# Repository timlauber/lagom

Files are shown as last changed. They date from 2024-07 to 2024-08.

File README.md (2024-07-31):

# lagom
Lagom is an easy to build 65% keyboard using ~~only~~ some through hole components. It uses a separate microcontroller (like the Pro Micro, Elite C or something RP2040 based) to enable flexibility in firmware and connectivity and to further simplify the soldering experience (no more tricksy USB ports). Demultiplexers and a custom matrix are used to enable the size and features of the board with only the pinouts of a pro micro.

## Changes
This version replaces most trough hole components for SMD variants, but keeps visuals. A power switch as well as a battery connector is added for full wireless support. Only ISO layout is supported.

lagom

**Original lagom kits are available for sale at [sthlmkb.com](https://sthlmkb.com/shop/lagom-keyboard-kit/)**

[License](LICENSE)

Lagom is licensed under the [Creative Commons Attribution-NonCommercial 4.0 International license](https://creativecommons.org/licenses/by-nc/4.0/). This design as it stands in this repository may be freely reproduced, modified, and manufactured for PERSONAL USE ONLY and may not be reproduced in physical form for public sale. 

## Features
* ~~Only through hole components for easy soldering~~
* Separate microcontroller using Pro micro, Elite C, Nice! Nano or equivalent footprint. So micro USB, USB-C or Bluetooth are all options!
* 2 rotary encoders
* OLED screen
* Optional underglow RGB lighting with a WS2812b light strip
* ~~Multiple layout options including ISO, ANSI, split space (2.25u + 1.25u + 2.75u), 7u space, split left shift (1.25u + 1u) and stepped capslock ([layout]("http://www.keyboard-layout-editor.com/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,15&_x:0.25%3B&=2,15&_x:0.25%3B&=0,0%0A%0A%0A%0A%0A%0A%0A%0A%0Ae&=0,1%0A%0A%0A%0A%0A%0A%0A%0A%0Ae%3B&@_y:0.25%3B&=0,0&=0,1&=0,2&=0,3&=0,4&=0,5&=0,6&=0,7&=0,8&=0,9&=0,10&=0,11&=0,12&_w:2%3B&=0,14%0A%0A%0A0,0&=0,15&_x:0.25%3B&=1,0%0A%0A%0A%0A%0A%0A%0A%0A%0Ae&=1,1%0A%0A%0A%0A%0A%0A%0A%0A%0Ae%3B&@_w:1.5%3B&=1,0&=1,1&=1,2&=1,3&=1,4&=1,5&=1,6&=1,7&=1,8&=1,9&=1,10&=1,11&=1,12&_w:1.5%3B&=1,13%0A%0A%0A1,0&=1,14%3B&@_w:1.75%3B&=2,0&=2,1&=2,2&=2,3&=2,4&=2,5&=2,6&=2,7&=2,8&=2,9&=2,10&=2,11&_w:2.25%3B&=2,13%0A%0A%0A1,0&=2,14%3B&@_w:2.25%3B&=3,0%0A%0A%0A2,0&=3,2&=3,3&=3,4&=3,5&=3,6&=3,7&=3,8&=3,9&=3,10&=3,11&_w:1.75%3B&=3,12&=3,13&=3,14%3B&@_w:1.25%3B&=4,0%0A%0A%0A3,0&_w:1.25%3B&=4,1%0A%0A%0A3,0&_w:1.25%3B&=4,2%0A%0A%0A3,0&_w:6.25%3B&=4,6%0A%0A%0A3,0&_w:1.25%3B&=4,10%0A%0A%0A3,0&_w:1.25%3B&=4,11%0A%0A%0A3,0&_x:0.5%3B&=4,12&=4,13&=4,14%3B&@_y:0.5&w:1.25%3B&=4,0%0A%0A%0A3,1&_w:1.25%3B&=4,1%0A%0A%0A3,1&_w:1.25%3B&=4,2%0A%0A%0A3,1&_w:2.25%3B&=4,4%0A%0A%0A3,1&_w:1.25%3B&=4,6%0A%0A%0A3,1&_w:2.75%3B&=4,8%0A%0A%0A3,1&_w:1.25%3B&=4,10%0A%0A%0A3,1&_w:1.25%3B&=4,11%0A%0A%0A3,1%3B&@_y:-0.25&x:15&w:1.25&h:2&w2:1.5&h2:1&x2:-0.25%3B&=2,13%0A%0A%0A1,1%3B&@_y:-0.75&w:1.5%3B&=4,0%0A%0A%0A3,2&=4,1%0A%0A%0A3,2&_w:1.5%3B&=4,2%0A%0A%0A3,2&_w:7%3B&=4,6%0A%0A%0A3,2&_w:1.5%3B&=4,11%0A%0A%0A3,2%3B&@_y:-0.25&x:14%3B&=2,12%0A%0A%0A1,1%3B&@_w:1.25%3B&=3,0%0A%0A%0A2,1&=3,1%0A%0A%0A2,1&_x:9.75%3B&=0,13%0A%0A%0A0,1&=0,14%0A%0A%0A0,1"))~~
* Open and visible components (in the style of Plaid, Romac etc)
* Simple, beautiful and flexible sandwich case out of FR4 (pcb material)

lagom layout

## Components required - To be determined!
* PCB
* FR4 Switch plate
* FR4 Base 
* Controller (I used a Pro Micro in the guide but anything that shares the footprint and pinout will be fine e.g. Elite C, Nice! Nano, or something RP2040 powered!)
* Diodes 1N4148 (74)
* 0.1μF Capacitor (2)
* 16 pin IC socket (2)
* IC (74HC138N) demultiplexer (2)
* Switches (5 pin MX footprint) (up to 72 depending on layout)
* Rotary encoders (2)
* Rotary encoder knobs (2)
* 0.91" OLED screen
* 10mm M2 Standoffs (9 required if mounting the base to the plate)
* 6mm x M2 screws for attaching the standoffs to the plate/base (2 per standoff so 18 total)
* Acrylic cover for the components at the top (optional, not included)
* Stabilisers (PCB mount) (5 x 2u or 3 x 2u + 6.25u or 3 x 2u + 7u depending on layout)
* Rubber feet for the base

Build guide for this version is not available.
[Original build guide available here](https://github.com/mohoyt/lagom/blob/main/build_guide.md)

lagom base

lagom lagom pcb

## Known issues 
None yet! 

## Where to buy
Lagom kits are available for sale exclusively at [sthlmkb.com](https://sthlmkb.com/shop/lagom-keyboard-kit/)

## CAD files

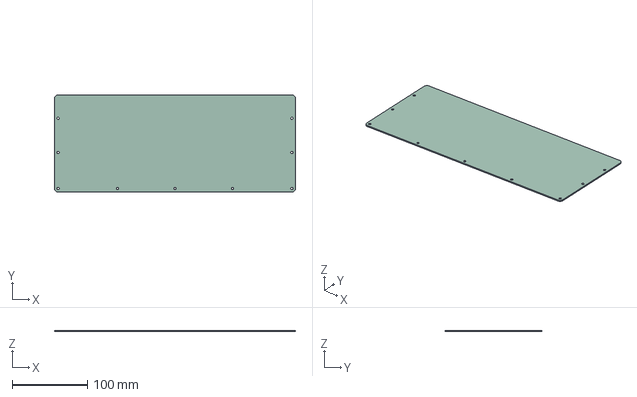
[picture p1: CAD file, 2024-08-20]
PCB/lagom_base/lagom_base.step
319.9 x 128.9 x 1.60 mm

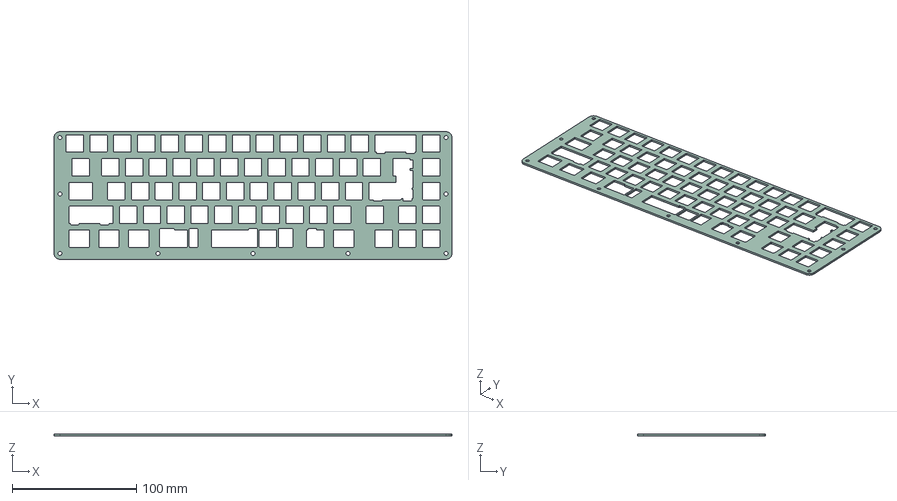
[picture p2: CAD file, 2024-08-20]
PCB/lagom_plate/lagom_plate.step
319.9 x 102.7 x 1.60 mm

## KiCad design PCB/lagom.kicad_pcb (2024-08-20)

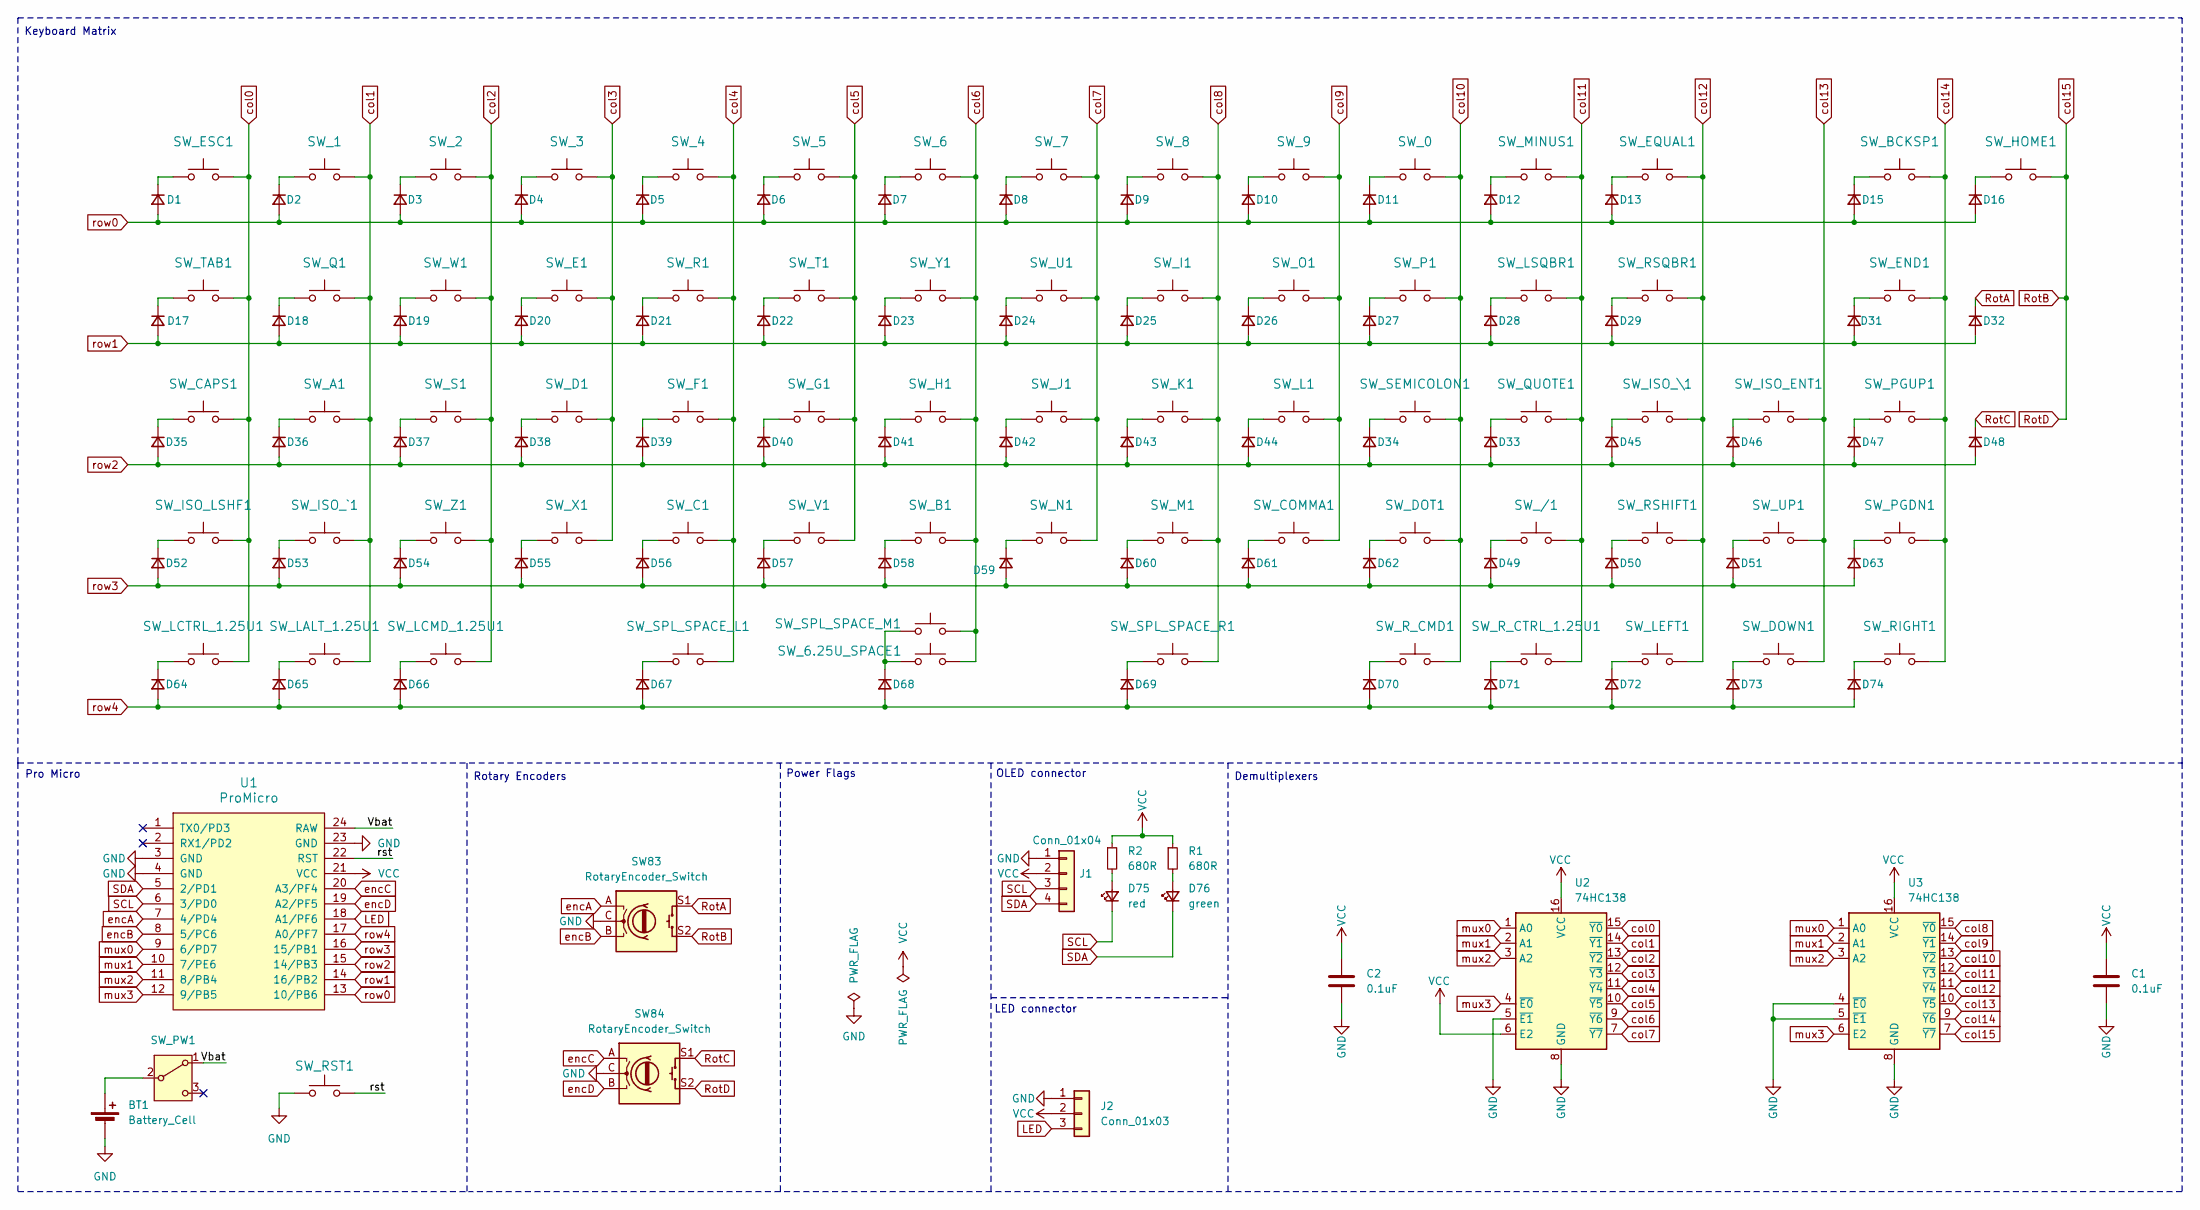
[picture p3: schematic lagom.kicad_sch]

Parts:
BT1: Battery_Cell; JST_PH_S2B-PH-K_1x02_P2.00mm_Horizontal
C1, C2: 0.1uF; C_0805_2012Metric
D1, D2, D3, D4, D5, D6, D7, D8, D9, D10, D11, D12, D13, D15, D16, D17, D18, D19, D20, D21, D22, D23, D24, D25, D26, D27, D28, D29, D31, D32, D33, D34, D35, D36, D37, D38, D39, D40, D41, D42, D43, D44, D45, D46, D47, D48, D49, D50, D51, D52, D53, D54, D55, D56, D57, D58, D59, D60, D61, D62, D63, D64, D65, D66, D67, D68, D69, D70, D71, D72, D73, D74: 1N4148; D_MiniMELF_noSilk
D75: red; LED_1206_3216Metric
D76: green; LED_1206_3216Metric
J1: Conn_01x04; PinSocket_1x04_P2.54mm_Vertical
J2: Conn_01x03; PinSocket_1x03_P2.54mm_Vertical
R1, R2: 680R; R_1206_3216Metric
SW83, SW84: RotaryEncoder_Switch; RotaryEncoder_Alps_EC11E-Switch_Vertical_H20mm
SW_0, SW_1, SW_2, SW_3, SW_4, SW_5, SW_6, SW_7, SW_8, SW_9: KEYSW; SW_Kailh_HotSwap_1.00u_PCB
SW_6.25U_SPACE1: KEYSW; SW_Kailh_HotSwap_6.25u_PCB_reverse
SW_/1: KEYSW; SW_Kailh_HotSwap_1.00u_PCB
SW_A1: KEYSW; SW_Kailh_HotSwap_1.00u_PCB
SW_B1: KEYSW; SW_Kailh_HotSwap_1.00u_PCB
SW_BCKSP1: KEYSW; SW_Kailh_HotSwap_2.00u_PCB
SW_C1: KEYSW; SW_Kailh_HotSwap_1.00u_PCB
SW_CAPS1: KEYSW; SW_Kailh_HotSwap_1.75u_PCB
SW_COMMA1: KEYSW; SW_Kailh_HotSwap_1.00u_PCB
SW_D1: KEYSW; SW_Kailh_HotSwap_1.00u_PCB
SW_DOT1: KEYSW; SW_Kailh_HotSwap_1.00u_PCB
SW_DOWN1: KEYSW; SW_Kailh_HotSwap_1.00u_PCB
SW_E1: KEYSW; SW_Kailh_HotSwap_1.00u_PCB
SW_END1: KEYSW; SW_Kailh_HotSwap_1.00u_PCB
SW_EQUAL1: KEYSW; SW_Kailh_HotSwap_1.00u_PCB
SW_ESC1: KEYSW; SW_Kailh_HotSwap_1.00u_PCB
SW_F1: KEYSW; SW_Kailh_HotSwap_1.00u_PCB
SW_G1: KEYSW; SW_Kailh_HotSwap_1.00u_PCB
SW_H1: KEYSW; SW_Kailh_HotSwap_1.00u_PCB
SW_HOME1: KEYSW; SW_Kailh_HotSwap_1.00u_PCB
SW_I1: KEYSW; SW_Kailh_HotSwap_1.00u_PCB
SW_ISO_ENT1: KEYSW; SW_Kailh_HotSwap_ISOEnter_PCB
SW_ISO_LSHF1: KEYSW; SW_Kailh_HotSwap_1.25u_PCB
SW_ISO_\1: KEYSW; SW_Kailh_HotSwap_1.00u_PCB
SW_ISO_`1: KEYSW; SW_Kailh_HotSwap_1.00u_PCB
SW_J1: KEYSW; SW_Kailh_HotSwap_1.00u_PCB
SW_K1: KEYSW; SW_Kailh_HotSwap_1.00u_PCB
SW_L1: KEYSW; SW_Kailh_HotSwap_1.00u_PCB
SW_LALT_1.25U1: KEYSW; SW_Kailh_HotSwap_1.25u_PCB
SW_LCMD_1.25U1: KEYSW; SW_Kailh_HotSwap_1.25u_PCB
SW_LCTRL_1.25U1: KEYSW; SW_Kailh_HotSwap_1.25u_PCB
SW_LEFT1: KEYSW; SW_Kailh_HotSwap_1.00u_PCB
SW_LSQBR1: KEYSW; SW_Kailh_HotSwap_1.00u_PCB
SW_M1: KEYSW; SW_Kailh_HotSwap_1.00u_PCB
SW_MINUS1: KEYSW; SW_Kailh_HotSwap_1.00u_PCB
SW_N1: KEYSW; SW_Kailh_HotSwap_1.00u_PCB
SW_O1: KEYSW; SW_Kailh_HotSwap_1.00u_PCB
SW_P1: KEYSW; SW_Kailh_HotSwap_1.00u_PCB
SW_PGDN1: KEYSW; SW_Kailh_HotSwap_1.00u_PCB
SW_PGUP1: KEYSW; SW_Kailh_HotSwap_1.00u_PCB
SW_PW1: SW_SPDT; PinHeader_1x03_P2.54mm_Vertical
SW_Q1: KEYSW; SW_Kailh_HotSwap_1.00u_PCB
SW_QUOTE1: KEYSW; SW_Kailh_HotSwap_1.00u_PCB
SW_R1: KEYSW; SW_Kailh_HotSwap_1.00u_PCB
SW_RIGHT1: KEYSW; SW_Kailh_HotSwap_1.00u_PCB
SW_RSHIFT1: KEYSW; SW_Kailh_HotSwap_1.75u_PCB
SW_RSQBR1: KEYSW; SW_Kailh_HotSwap_1.00u_PCB
SW_RST1: KEYSW; SW_PUSH_1P1T_6x3.5mm_H5.0_APEM_MJTP1250
SW_R_CMD1: KEYSW; SW_Kailh_HotSwap_1.25u_PCB
SW_R_CTRL_1.25U1: KEYSW; SW_Kailh_HotSwap_1.25u_PCB
SW_S1: KEYSW; SW_Kailh_HotSwap_1.00u_PCB
SW_SEMICOLON1: KEYSW; SW_Kailh_HotSwap_1.00u_PCB
SW_SPL_SPACE_L1: KEYSW; SW_Kailh_HotSwap_2.25u_PCB_reverse
SW_SPL_SPACE_M1: KEYSW; SW_Kailh_HotSwap_1.25u_PCB
SW_SPL_SPACE_R1: KEYSW; SW_Kailh_HotSwap_2.75u_PCB_reverse
SW_T1: KEYSW; SW_Kailh_HotSwap_1.00u_PCB
SW_TAB1: KEYSW; SW_Kailh_HotSwap_1.50u_PCB
SW_U1: KEYSW; SW_Kailh_HotSwap_1.00u_PCB
SW_UP1: KEYSW; SW_Kailh_HotSwap_1.00u_PCB
SW_V1: KEYSW; SW_Kailh_HotSwap_1.00u_PCB
SW_W1: KEYSW; SW_Kailh_HotSwap_1.00u_PCB
SW_X1: KEYSW; SW_Kailh_HotSwap_1.00u_PCB
SW_Y1: KEYSW; SW_Kailh_HotSwap_1.00u_PCB
SW_Z1: KEYSW; SW_Kailh_HotSwap_1.00u_PCB
U1: ProMicro; ArduinoProMicro-ZigZag
U2, U3: 74HC138; SOIC-16_3.9x9.9mm_P1.27mm

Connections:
/Vbat: SW_PW1.1 (A), U1.24 (RAW)
/rst: SW_RST1.2, U1.22 (RST)
GND: BT1.2 (-), C1.2, C2.2, J1.1, J2.1, SW83.C, SW84.C, SW_RST1.1, U1.3 (GND), U1.4 (GND), U1.23 (GND), U2.5 (~E1), U2.8 (GND), U3.4 (~E0), U3.5 (~E1), U3.8 (GND)
LED: J2.3, U1.18 (A1/PF6)
unnamed: BT1.1 (+), SW_PW1.2 (B)
unnamed: D1.1 (K), SW_ESC1.1
unnamed: D2.1 (K), SW_1.1
unnamed: D3.1 (K), SW_2.1
unnamed: D4.1 (K), SW_3.1
unnamed: D5.1 (K), SW_4.1
unnamed: D6.1 (K), SW_5.1
unnamed: D7.1 (K), SW_6.1
unnamed: D8.1 (K), SW_7.1
unnamed: D9.1 (K), SW_8.1
unnamed: D10.1 (K), SW_9.1
unnamed: D11.1 (K), SW_0.1
unnamed: D12.1 (K), SW_MINUS1.1
unnamed: D13.1 (K), SW_EQUAL1.1
unnamed: D15.1 (K), SW_BCKSP1.1
unnamed: D16.1 (K), SW_HOME1.1
unnamed: D17.1 (K), SW_TAB1.1
unnamed: D18.1 (K), SW_Q1.1
unnamed: D19.1 (K), SW_W1.1
unnamed: D20.1 (K), SW_E1.1
unnamed: D21.1 (K), SW_R1.1
unnamed: D22.1 (K), SW_T1.1
unnamed: D23.1 (K), SW_Y1.1
unnamed: D24.1 (K), SW_U1.1
unnamed: D25.1 (K), SW_I1.1
unnamed: D26.1 (K), SW_O1.1
unnamed: D27.1 (K), SW_P1.1
unnamed: D28.1 (K), SW_LSQBR1.1
unnamed: D29.1 (K), SW_RSQBR1.1
unnamed: D31.1 (K), SW_END1.1
unnamed: D33.1 (K), SW_QUOTE1.1
unnamed: D34.1 (K), SW_SEMICOLON1.1
unnamed: D35.1 (K), SW_CAPS1.1
unnamed: D36.1 (K), SW_A1.1
unnamed: D37.1 (K), SW_S1.1
unnamed: D38.1 (K), SW_D1.1
unnamed: D39.1 (K), SW_F1.1
unnamed: D40.1 (K), SW_G1.1
unnamed: D41.1 (K), SW_H1.1
unnamed: D42.1 (K), SW_J1.1
unnamed: D43.1 (K), SW_K1.1
unnamed: D44.1 (K), SW_L1.1
unnamed: D45.1 (K), SW_ISO_\1.1
unnamed: D46.1 (K), SW_ISO_ENT1.1
unnamed: D47.1 (K), SW_PGUP1.1
unnamed: D49.1 (K), SW_/1.1
unnamed: D50.1 (K), SW_RSHIFT1.1
unnamed: D51.1 (K), SW_UP1.1
unnamed: D52.1 (K), SW_ISO_LSHF1.1
unnamed: D53.1 (K), SW_ISO_`1.1
unnamed: D54.1 (K), SW_Z1.1
unnamed: D55.1 (K), SW_X1.1
unnamed: D56.1 (K), SW_C1.1
unnamed: D57.1 (K), SW_V1.1
unnamed: D58.1 (K), SW_B1.1
unnamed: D59.1 (K), SW_N1.1
unnamed: D60.1 (K), SW_M1.1
unnamed: D61.1 (K), SW_COMMA1.1
unnamed: D62.1 (K), SW_DOT1.1
unnamed: D63.1 (K), SW_PGDN1.1
unnamed: D64.1 (K), SW_LCTRL_1.25U1.1
unnamed: D65.1 (K), SW_LALT_1.25U1.1
unnamed: D66.1 (K), SW_LCMD_1.25U1.1
unnamed: D67.1 (K), SW_SPL_SPACE_L1.1
unnamed: D68.1 (K), SW_6.25U_SPACE1.1, SW_SPL_SPACE_M1.2
unnamed: D69.1 (K), SW_SPL_SPACE_R1.1
unnamed: D70.1 (K), SW_R_CMD1.1
unnamed: D71.1 (K), SW_R_CTRL_1.25U1.1
unnamed: D72.1 (K), SW_LEFT1.1
unnamed: D73.1 (K), SW_DOWN1.1
unnamed: D74.1 (K), SW_RIGHT1.1
unnamed: D75.2 (A), R2.2
unnamed: D76.2 (A), R1.2
RotA: D32.1 (K), SW83.S1
RotB: SW83.S2, SW84.S2, SW_HOME1.2, U3.7 (~Y7)
RotC: D48.1 (K), SW84.S1
SCL: D75.1 (K), J1.3, U1.6 (3/PD0)
SDA: D76.1 (K), J1.4, U1.5 (2/PD1)
VCC: C1.1, C2.1, J1.2, J2.2, R1.1, R2.1, U1.21 (VCC), U2.6 (E2), U2.16 (VCC), U3.16 (VCC)
col0: SW_CAPS1.2, SW_ESC1.2, SW_ISO_LSHF1.2, SW_LCTRL_1.25U1.2, SW_TAB1.2, U2.15 (~Y0)
col1: SW_1.2, SW_A1.2, SW_ISO_`1.2, SW_LALT_1.25U1.2, SW_Q1.2, U2.14 (~Y1)
col2: SW_2.2, SW_LCMD_1.25U1.2, SW_S1.2, SW_W1.2, SW_Z1.2, U2.13 (~Y2)
col3: SW_3.2, SW_D1.2, SW_E1.2, SW_X1.2, U2.12 (~Y3)
col4: SW_4.2, SW_C1.2, SW_F1.2, SW_R1.2, SW_SPL_SPACE_L1.2, U2.11 (~Y4)
col5: SW_5.2, SW_G1.2, SW_T1.2, SW_V1.2, U2.10 (~Y5)
col6: SW_6.2, SW_6.25U_SPACE1.2, SW_B1.2, SW_H1.2, SW_SPL_SPACE_M1.1, SW_Y1.2, U2.9 (~Y6)
col7: SW_7.2, SW_J1.2, SW_N1.2, SW_U1.2, U2.7 (~Y7)
col8: SW_8.2, SW_I1.2, SW_K1.2, SW_M1.2, SW_SPL_SPACE_R1.2, U3.15 (~Y0)
col9: SW_9.2, SW_COMMA1.2, SW_L1.2, SW_O1.2, U3.14 (~Y1)
col10: SW_0.2, SW_DOT1.2, SW_P1.2, SW_R_CMD1.2, SW_SEMICOLON1.2, U3.13 (~Y2)
col11: SW_/1.2, SW_LSQBR1.2, SW_MINUS1.2, SW_QUOTE1.2, SW_R_CTRL_1.25U1.2, U3.12 (~Y3)
col12: SW_EQUAL1.2, SW_ISO_\1.2, SW_LEFT1.2, SW_RSHIFT1.2, SW_RSQBR1.2, U3.11 (~Y4)
col13: SW_DOWN1.2, SW_ISO_ENT1.2, SW_UP1.2, U3.10 (~Y5)
col14: SW_BCKSP1.2, SW_END1.2, SW_PGDN1.2, SW_PGUP1.2, SW_RIGHT1.2, U3.9 (~Y6)
encA: SW83.A, U1.7 (4/PD4)
encB: SW83.B, U1.8 (5/PC6)
encC: SW84.A, U1.20 (A3/PF4)
encD: SW84.B, U1.19 (A2/PF5)
mux0: U1.9 (6/PD7), U2.1 (A0), U3.1 (A0)
mux1: U1.10 (7/PE6), U2.2 (A1), U3.2 (A1)
mux2: U1.11 (8/PB4), U2.3 (A2), U3.3 (A2)
mux3: U1.12 (9/PB5), U2.4 (~E0), U3.6 (E2)
row0: D1.2 (A), D2.2 (A), D3.2 (A), D4.2 (A), D5.2 (A), D6.2 (A), D7.2 (A), D8.2 (A), D9.2 (A), D10.2 (A), D11.2 (A), D12.2 (A), D13.2 (A), D15.2 (A), D16.2 (A), U1.13 (10/PB6)
row1: D17.2 (A), D18.2 (A), D19.2 (A), D20.2 (A), D21.2 (A), D22.2 (A), D23.2 (A), D24.2 (A), D25.2 (A), D26.2 (A), D27.2 (A), D28.2 (A), D29.2 (A), D31.2 (A), D32.2 (A), U1.14 (16/PB2)
row2: D33.2 (A), D34.2 (A), D35.2 (A), D36.2 (A), D37.2 (A), D38.2 (A), D39.2 (A), D40.2 (A), D41.2 (A), D42.2 (A), D43.2 (A), D44.2 (A), D45.2 (A), D46.2 (A), D47.2 (A), D48.2 (A), U1.15 (14/PB3)
row3: D49.2 (A), D50.2 (A), D51.2 (A), D52.2 (A), D53.2 (A), D54.2 (A), D55.2 (A), D56.2 (A), D57.2 (A), D58.2 (A), D59.2 (A), D60.2 (A), D61.2 (A), D62.2 (A), D63.2 (A), U1.16 (15/PB1)
row4: D64.2 (A), D65.2 (A), D66.2 (A), D67.2 (A), D68.2 (A), D69.2 (A), D70.2 (A), D71.2 (A), D72.2 (A), D73.2 (A), D74.2 (A), U1.17 (A0/PF7)

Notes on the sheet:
OLED connector
Rotary Encoders
Keyboard Matrix
Power Flags
LED connector
Pro Micro
Demultiplexers

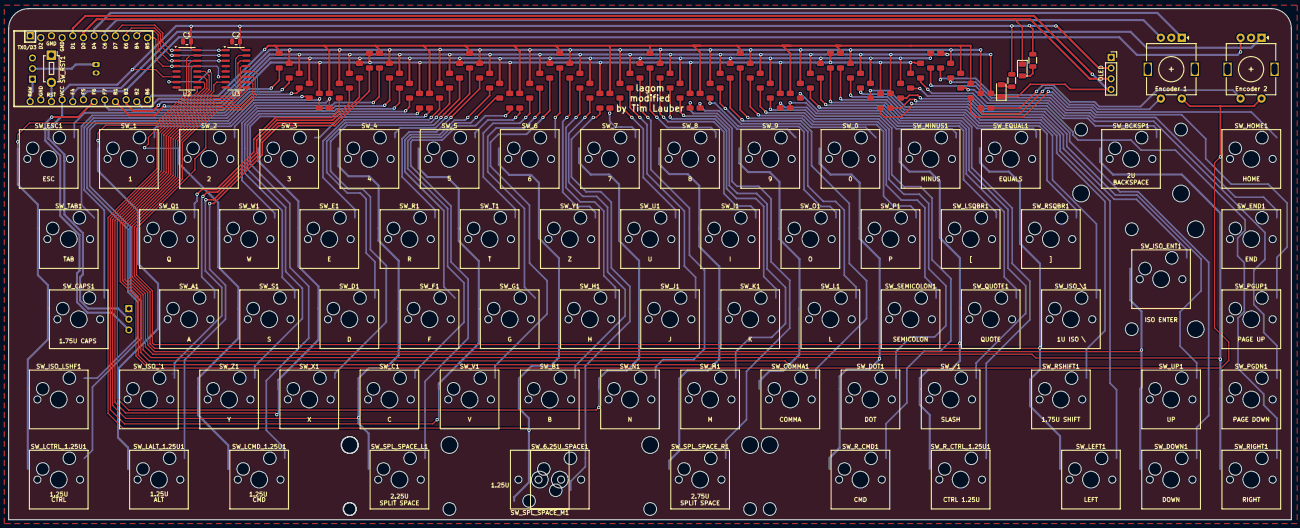
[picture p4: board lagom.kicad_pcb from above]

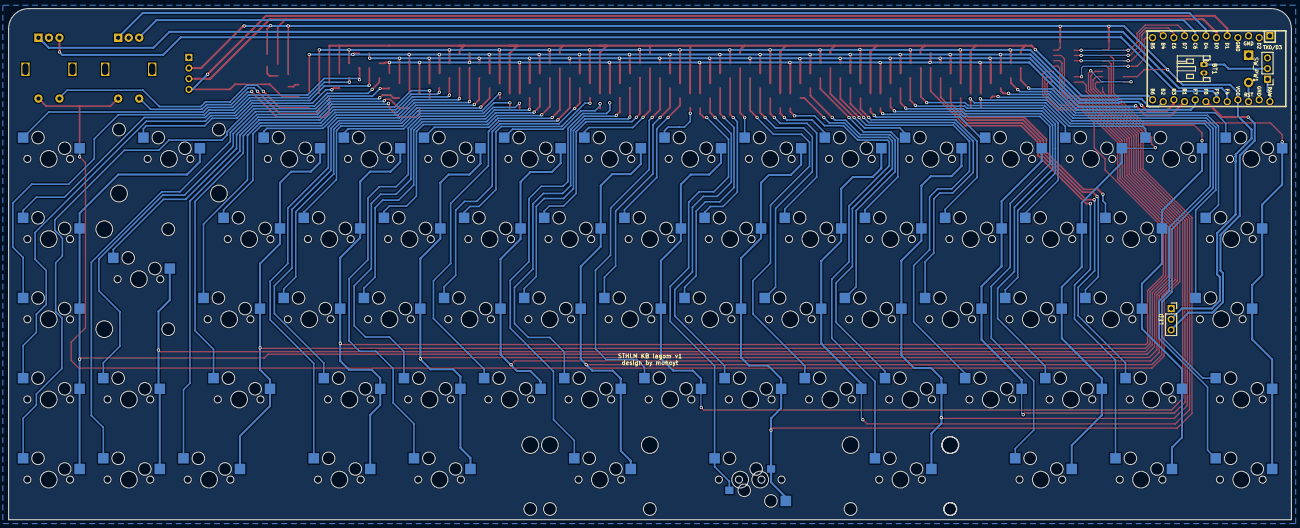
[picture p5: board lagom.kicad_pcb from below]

Board: 2 copper layers, 305.6 x 121.8 mm, 159 parts (4 on the bottom side), 111 nets.

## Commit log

2024-07-31 Remove legacy gerber outputs
    [lagom-B_Cu.gbl, lagom-B_Mask.gbs, lagom-B_Paste.gbp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]
2024-07-31 Update main pcb kicad to KiCAD8
    [lagom.kicad_sch]
2024-07-31 Remove legacy KiCAD backups and dont version them anymore
2024-07-31 Replace 74hc138 symbol with standard library symbol and remove custom library
    [lagom.kicad_sch]
2024-07-31 Demultiplexer footprint -> TSSOP16
    [lagom.kicad_sch]
2024-07-31 Remove optional ANSI from schematic
    [lagom.kicad_sch]
2024-07-31 Standard SW_PUSH symbol. Remove unused library and submodule
    [lagom.kicad_sch]
2024-07-31 Add battery connector, reset and power switch to schematic
    [lagom.kicad_sch]
2024-07-31 Remove symbol libraries from footprint library table
2024-08-01 All Diodes 1N4148 type
    [lagom.kicad_sch]
2024-08-01 Capacitor fp -> 0805
    [lagom.kicad_sch]
2024-08-01 main schematic: Change switch footprints to hotswap, add custom switch fp library
    [lagom.kicad_sch]
2024-08-01 Change promicro symbol to local and remove dependency of keebio sym lib
    [lagom.kicad_sch]
2024-08-01 Schematic - Diode fp -> SMD MiniMELF
    [lagom.kicad_sch]
2024-08-08 Layout - Complete rework
    [lagom.kicad_pcb, lagom.kicad_sch]
2024-08-09 Add alternative LEDs instead of OLED
    [lagom.kicad_pcb, lagom.kicad_sch]
2024-08-11 plate pcb -> kicad v8
    [lagom_plate.kicad_pcb, lagom_plate.kicad_sch]
2024-08-11 plate - Remove section for oled and rotary encoder.
    [lagom_plate.kicad_pcb]
2024-08-11 Cleanup outline
    [lagom_plate.kicad_pcb]
2024-08-15 Change mounting equipment to M3 Hole + SMSI solder nuts
    [lagom_base.kicad_pcb, lagom_plate.kicad_pcb]
2024-08-20 Remove legacy base and plate gerber files
    [lagom_base-B_Cu.gbl, lagom_base-B_Mask.gbs, lagom_base-B_Paste.gbp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]
2024-08-20 Add fabrication outputs
    [lagom-B_Cu.gbl, lagom-B_Mask.gbs, lagom-B_Paste.gbp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]
2024-08-20 Add signature
    [lagom.kicad_pcb, lagom_base.kicad_pcb, lagom_plate.kicad_pcb]
